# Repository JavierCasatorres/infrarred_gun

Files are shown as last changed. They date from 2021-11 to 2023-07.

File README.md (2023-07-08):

# Infrarred_gun
The project is designed to use an ATTINY10 as driver for a (high? power) collimated IR LED (~950 nm, https://es.aliexpress.com/item/1005002310393752.html?spm=a2g0s.9042311.0.0.27e063c02eyOOF) to modulate signals such as it is done in laser tag games.
The receiver is a chinese universal receiver (VS838), which requires pulses of ~600-800 us modulated @ ~38 kHz.

## TRANSMITTER ##
PB1 pin is used to output a 38 kHz signal generated with Attiny timer TC0B (working at 1MHz, with a 8 MHz instruction clock and a /8 prescaler).
An specific PCB is designed to use 2 P channel MOSFETs to effectively __and__ (thus modulating) the carrier with the data signal, which is output from PB0 pin.
PB3 is used as input for a _trigger_ signal (nothing is output if the trigger is not pressed). PB2 is used to output an "overload" signal, which is set when the trigger is pulsed continuously for ~1 second, simulating an overheating of the gun. If overload is reached, a ~3s cooldown period is required

### IMPORTANT ###
ATTINY10 has only 3 usable I/O by default (PB0, PB1, PB2). It has, however, another pin which is usually used as a /RESET for the TPI programming interface (PB3).
The reset can be disabled by disabling the RSTDISBL fuse with AVRDUDE and USBASP (if it has been updated to support TPI):
-Ufuse:w:0xfe:m (see https://www.engbedded.com/fusecalc/ for reference).
However, once disabled the chip can no longer be programmed with the usual programer (USBASP). It is required that 12V are applied to the /RESET pin for the whole programming session. This has been achieved by creating a voltage converter which can be placed as an intermediate between the USBASP and the ATTINY10, converting the usual 0V of "enabling" reset into 12V (and the usual 5V into 0V) via the use of a NMOS:
```
        12V
       ____
        |
        Z
        Z 10 K
        Z
        |------> Vout
     ___|
     |
---> | NMOS
     |___
         |
         |
       __|__
        ___
         _
```         
However, note that wven though fuses are easily "programmed" (set to zero) with the AVRDUDE command, they cannot be "reset" (set to 1) with the equivalent AVRDUDE command, the only way to reset them as stated in the datasheet:

Erasing the Configuration Section
The algorithm for erasing the Configuration section is as follows:
1. Write the 0x14 (SECTION_ERASE) to the NVMCMD register
2. Start the erase operation by writing a dummy byte to the high byte of any word location inside the
configuration section
3. Wait until the NVMBSY bit has been cleared

This is (thankfully!) currently supported by AVRDUDE, as pointed out by https://www.avrfreaks.net/forum/svn-avrdude-supports-attiny45910-fuse-reset
Use AVRDUDE with the following command and the fuses shall be reset, so the chip will be responsive to usual programming:
-x section_config -e

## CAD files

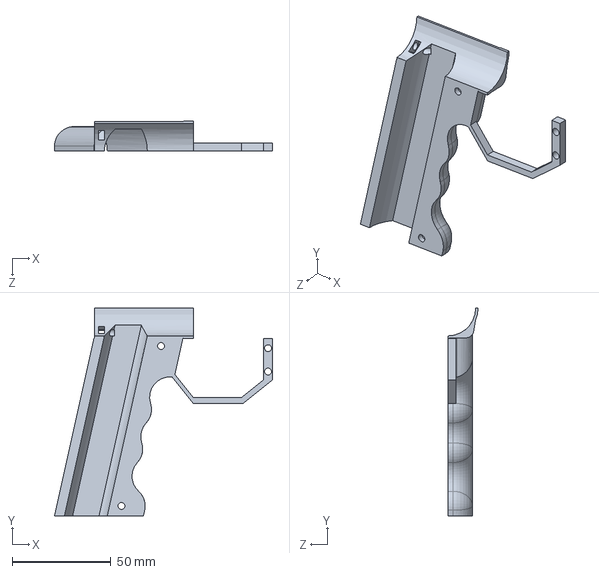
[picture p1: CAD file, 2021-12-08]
3D_designs/handle_left.SLDPRT
110.2 x 105.0 x 15.2 mm

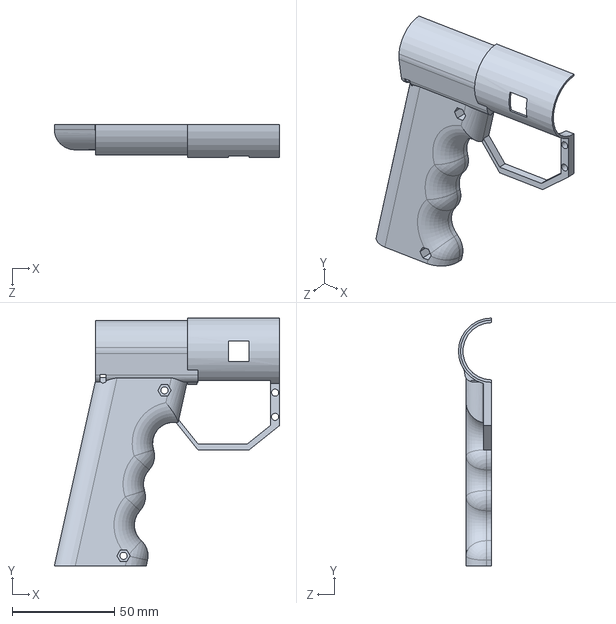
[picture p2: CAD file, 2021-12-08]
3D_designs/handle_right.SLDPRT
110.2 x 121.2 x 16.2 mm

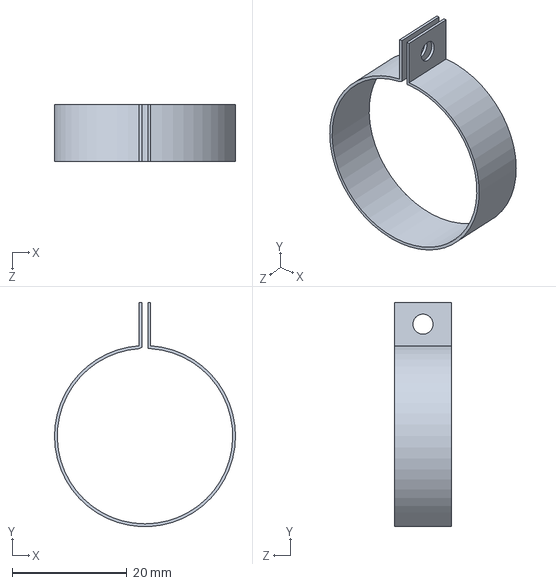
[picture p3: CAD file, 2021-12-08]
3D_designs/joint.SLDPRT
31.5 x 39.0 x 10.0 mm

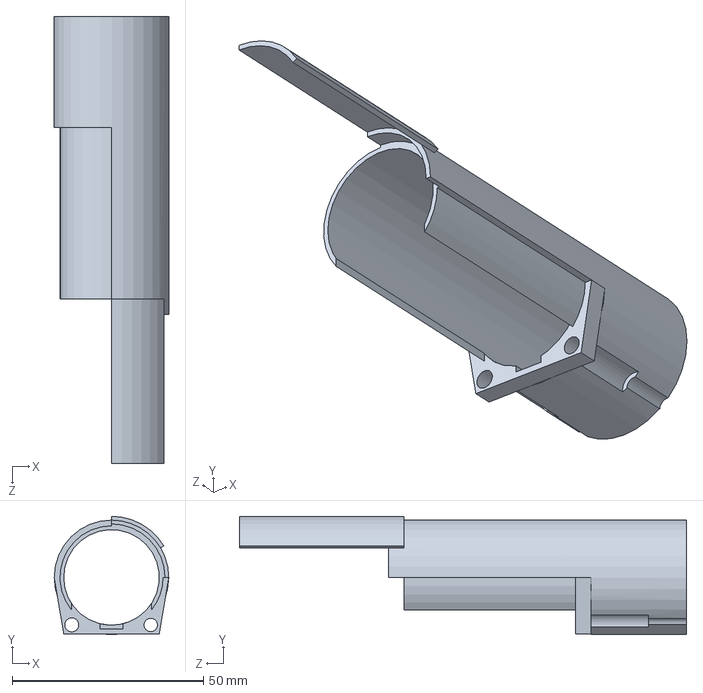
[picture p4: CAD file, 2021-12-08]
3D_designs/back.SLDPRT
30.0 x 31.0 x 117.0 mm

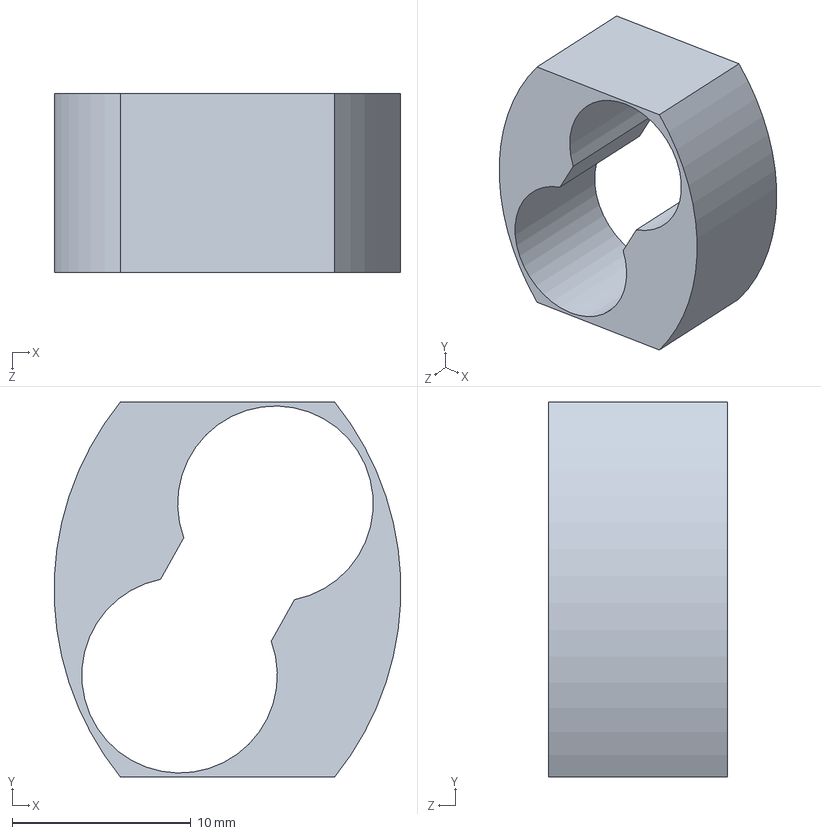
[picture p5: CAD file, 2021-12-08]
3D_designs/batteries_support.SLDPRT
19.4 x 21.0 x 10.0 mm

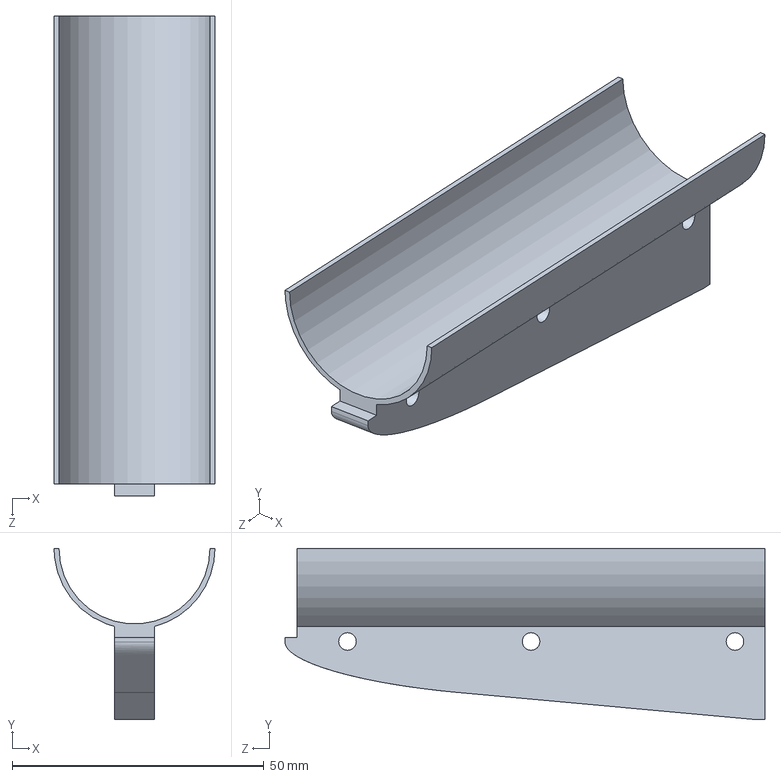
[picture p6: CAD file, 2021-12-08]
3D_designs/support.SLDPRT
32.0 x 34.0 x 95.4 mm

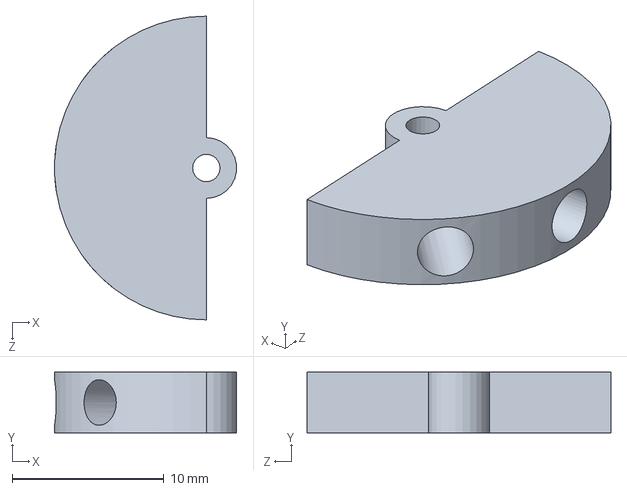
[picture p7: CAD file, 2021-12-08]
3D_designs/eccentric.SLDPRT
12.0 x 4.00 x 20.0 mm

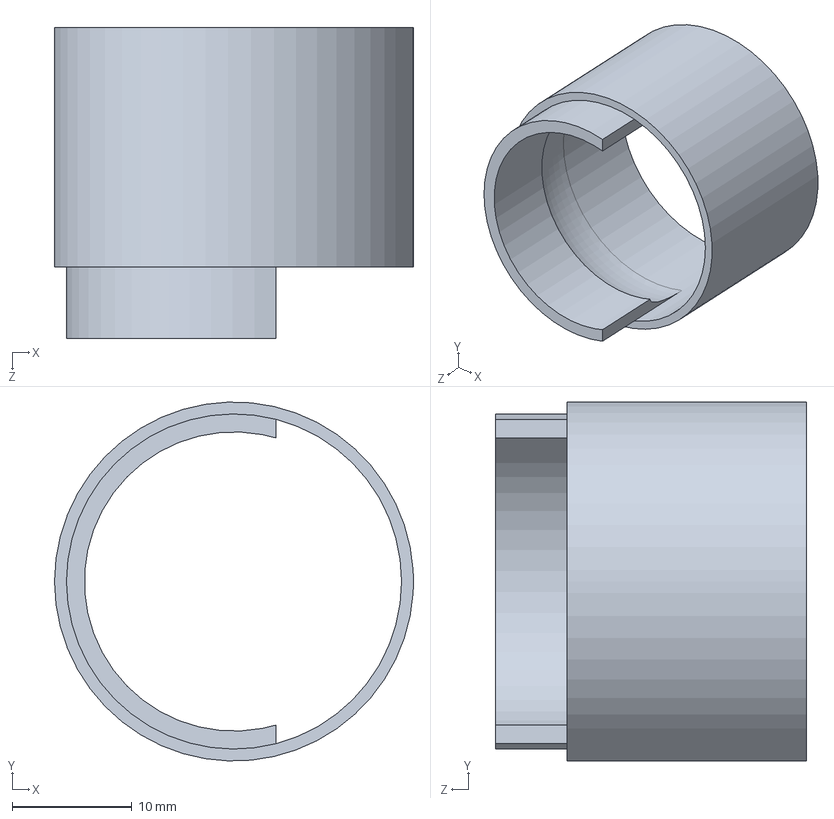
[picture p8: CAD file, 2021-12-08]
3D_designs/second_intermediate_support.SLDPRT
30.0 x 30.0 x 26.0 mm

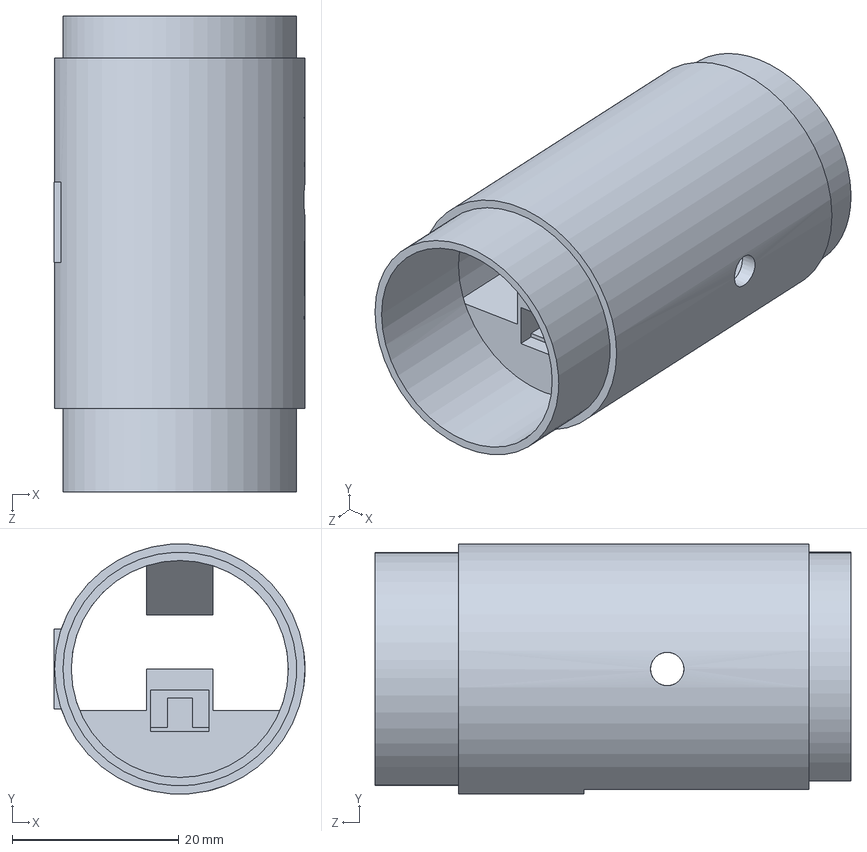
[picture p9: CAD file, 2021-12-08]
3D_designs/trigger_support_v2.SLDPRT
30.1 x 29.9 x 57.0 mm

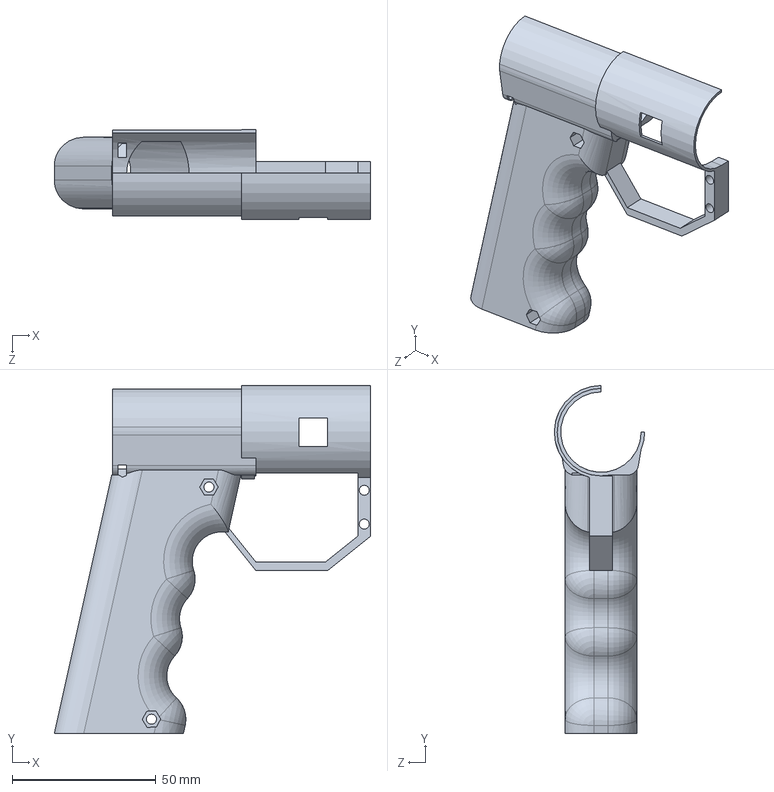
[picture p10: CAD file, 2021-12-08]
3D_designs/handle.SLDPRT
110.2 x 121.2 x 31.5 mm

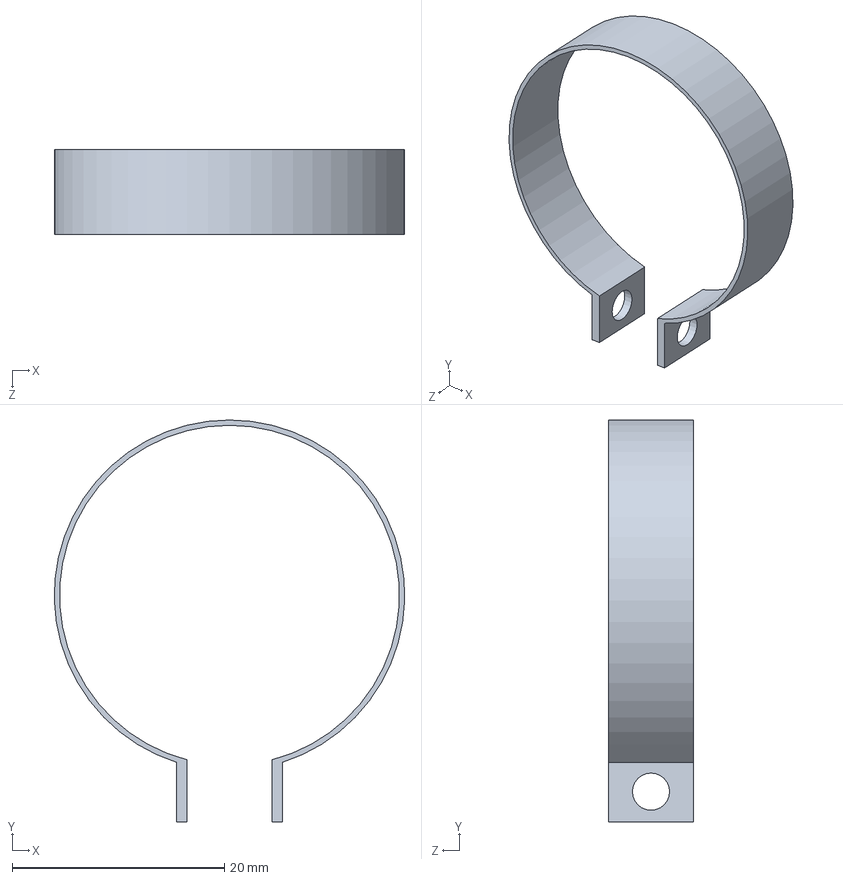
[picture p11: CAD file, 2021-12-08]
3D_designs/joint_2.SLDPRT
33.0 x 37.8 x 8.00 mm

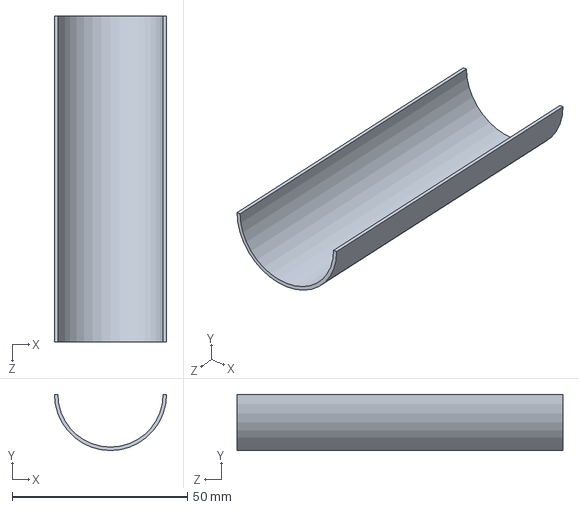
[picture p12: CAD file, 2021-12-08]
3D_designs/upper_cover.SLDPRT
32.0 x 16.0 x 93.0 mm

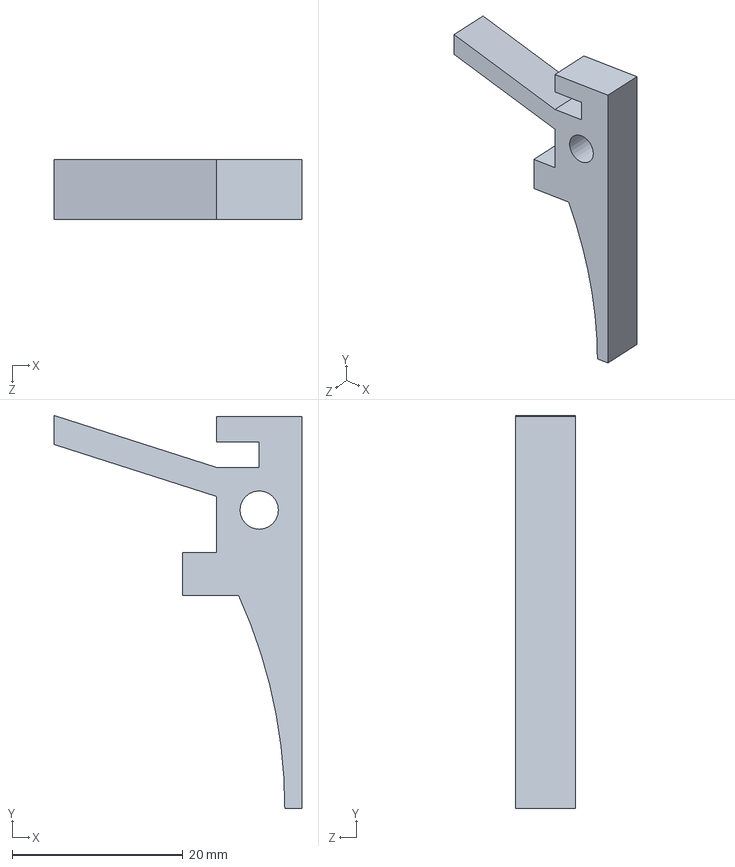
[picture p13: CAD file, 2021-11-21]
3D_designs/gun_trigger.SLDPRT
29.0 x 46.1 x 7.00 mm

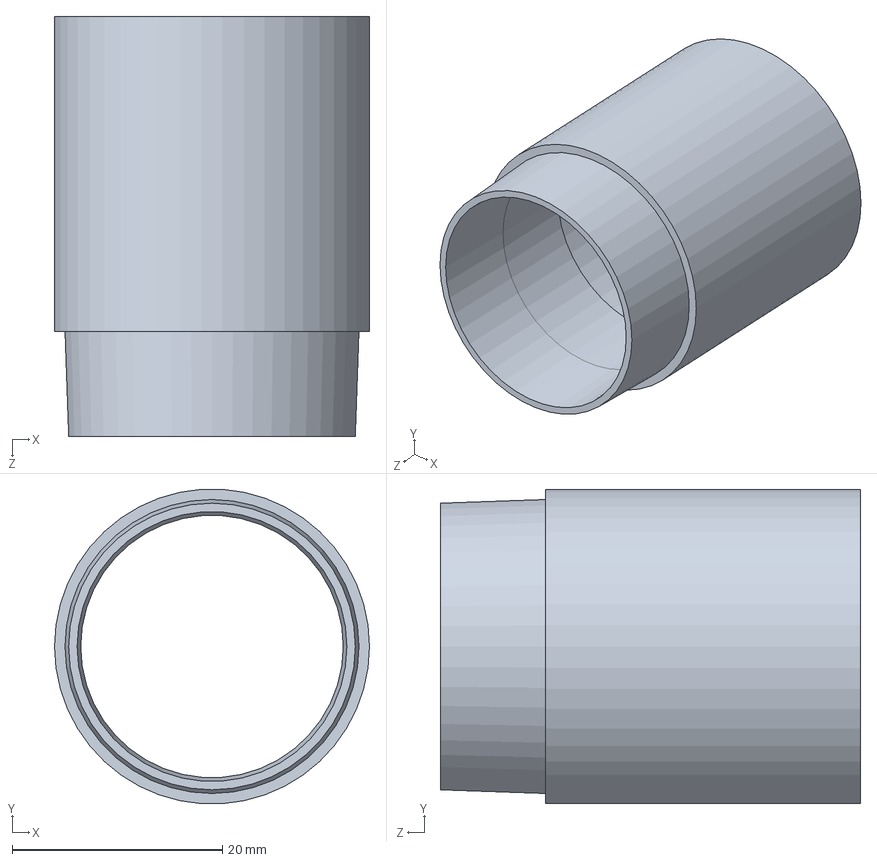
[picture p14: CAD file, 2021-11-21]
3D_designs/intermediate_support.SLDPRT
30.0 x 29.9 x 40.0 mm

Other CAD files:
3D_designs/trigger_support.SLDPRT
3D_designs/back.STL
3D_designs/batteries_support.STL
3D_designs/eccentric.STL
3D_designs/gun_trigger.STL
3D_designs/handle.STL
3D_designs/handle_left.STL
3D_designs/handle_right.STL
3D_designs/intermediate_support.STL
3D_designs/joint.STL
3D_designs/joint_2.STL
3D_designs/second_intermediate_support.STL
3D_designs/support.STL
3D_designs/trigger_support.STL
3D_designs/trigger_support_v2.STL
3D_designs/upper_cover.STL

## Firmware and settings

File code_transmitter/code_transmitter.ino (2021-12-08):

#define COUNT_LIMIT 15000
int count = 0, countaux = 0, enable_out = 0;
unsigned long count_button = 0;
int recharging = 0;
unsigned char arr_elem[64] = {
  1,1,1,0,0,1,1,1,0,0,1,1,1,0,0,1,
  1,1,1,1,1,1,1,1,1,1,1,1,1,1,1,1,
  1,1,1,1,1,1,1,1,1,1,1,1,1,1,1,1,
  1,1,1,1,1,1,1,1,1,1,1,1,1,1,1,1};
ISR(TIM0_COMPA_vect)
{
  // NOTE THAT THE SHOOTING VAL IS NEGATED as is connected to a PMOS
  count++;
  if (count == 15){ // At ~37.6 KHz, 11 cycles give about 300 us pulses, which is compatible with 600 and 900 us pulses
    count = 0;
    if(recharging == 0 and enable_out){
      if(enable_out){
        PORTB = (PORTB & (0xFE)) | (arr_elem[countaux]);
        if(count_button < COUNT_LIMIT)
          count_button+=3;
        countaux = (countaux + 1) & 0x0000003F; //This makes it module 32 easily
      }
    }
    else{ //Either forcefully recharging or "normal" recharging
      PORTB = (PORTB | 0x01); // Dont shoot
      if(count_button > 0)
        count_button--;
    }
  }  
}

void setup() {
  // Clock frequency can be changed by changing the prescaler value in CLKPSR (by default at /8)
  // Clock can even be calibrated to ensure 8 MHz frequency is achieved
  // Write the signature D8 in the CCP to unprotect CLKPSR
  CCP = 0xD8;
  CLKPSR = 0;


  // Configure both carrier output counter (counter B) and modulating signal output counter (counter A)
  DDRB = 0x7;                       // PB0, PB1 AND PB2 as an output. PB3 (reset) used as input
  TCCR0A = 0 << COM0A1 | 0 << COM0A0 | 1 << COM0B0 | 0 << WGM00;  // Toggle OC0B (channel B) in CTC mode, channel A works normally (as GPIO)
  TCCR0B = 1<<WGM02 | 2<<CS00;    // CTC mode; use OCR0A or OCR0B; Use /8 prescaler
  OCR0B = 12;                  // 12 gives a frequency of roughly 37.6 kHz for the carrier (channel B).
  OCR0A = 12;                  // Note that as the counter is RESET each time counter B reaches 12, the compare value for channel A
                               // cannot be higher than 12 or it shall never be reached. A value of 12 means interrupting at 37.6 KHz
                               // which is pretty high. Note that as the counter must reach 12 and the instructions are 8 times faster
                               // than the counter (because of the /8 value for the prescaler), 96 instructions shall execute in between
                               // interrupts
  //Configure interrupts
  //Enable interrupts globally
  asm("sei");
  //Enable interrupt on compare match in channel A  as
  TIMSK0 = 1 << OCIE0A;
}

void loop() {
  if (recharging == 0){
    PORTB = PORTB | 0x04; //Set the overload LED off (active low): logic OR with 0000 0100
    // When the button (PB3 port) is pushed, increase counter at a certain rate
    if(PINB & 0x08){
      enable_out = 1;
    }
    else{ 
      enable_out = 0;
    }
    if(count_button >= COUNT_LIMIT){
      recharging = 1;
      PORTB = PORTB & 0xFB; //Set the overload LED ON (active low): logic AND with 1111 1011
    }     
  }
  else{
    if(count_button == 0){
        recharging = 0;
    }
  }
}

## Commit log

2021-11-08 Fixes issue with the GPIO dedicated to the button, which is number 2 and not number 3 (which is dedicated to reset)
    [code_transmitter.ino]
2021-11-08 Adds instructions for disabling the /RESET to use the fourth IO pin in the chip
2021-11-08 Updates code to use PB3 (reset pin) as input to control trigger signal, and PB2 to indicate 'overload'. Timeouts are set at approximately 1 second to overload, and 3 seconds for cooldown
2021-11-10 Adds 3D designs
    [gun_trigger.SLDPRT, gun_trigger.STL, trigger_support.SLDPRT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]
2021-11-18 Updates 3d printed pieces
    [gun_trigger.SLDPRT, gun_trigger.STL, handle.SLDPRT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]
2021-11-26 Additional 3D files
    [handle.SLDPRT, handle_derecha.SLDPRT, handle_derecha.STL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]
2021-12-06 Parts updated
    [back.SLDPRT, back.STL, batteries_support.SLDPRT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]
2021-12-06 Renamed pieces
    [handle_left.SLDPRT, handle_left.STL, handle_right.SLDPRT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]
